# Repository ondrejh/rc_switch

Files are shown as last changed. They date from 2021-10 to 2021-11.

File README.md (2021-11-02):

RC signal (PWM) driven load switch
==================================

## Description

The device is using small mcu (cheapest possible MSP430FR2000) to decode RC signal and switch on the load NMOS tranzistor. Therefor its NPN switch (switching - or gnd).

PCB has no connectors. The servo (3 wires), battery (2 wires) and load (2 wires) cables are soldered directly to solder pads to save space and wheight.

The signal treshold and hysteresis is set in the code (see [main.c](/fw/main.c)). The polarity switching (high or low) can be set by soldering bridge marked "NEG".

## Hardware

### Schematic:

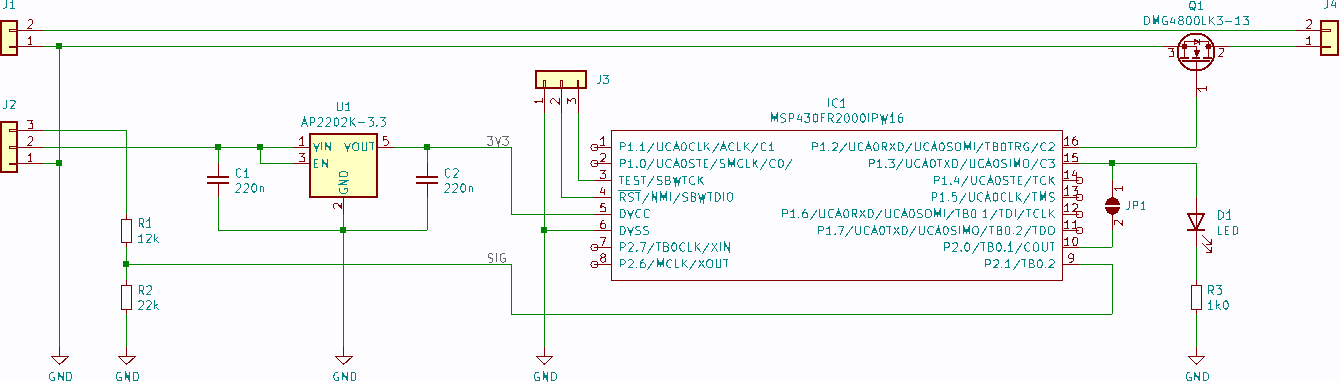
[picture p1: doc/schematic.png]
Schematic


### Assembled printed circuit (visualisation):

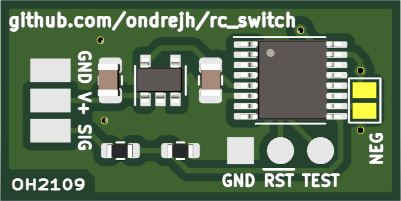
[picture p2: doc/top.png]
PCBA top

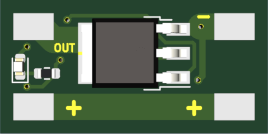
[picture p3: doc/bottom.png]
PCBA bottom


## ToDo:

- describe make process and tools
- describe programming
- create GIF demo

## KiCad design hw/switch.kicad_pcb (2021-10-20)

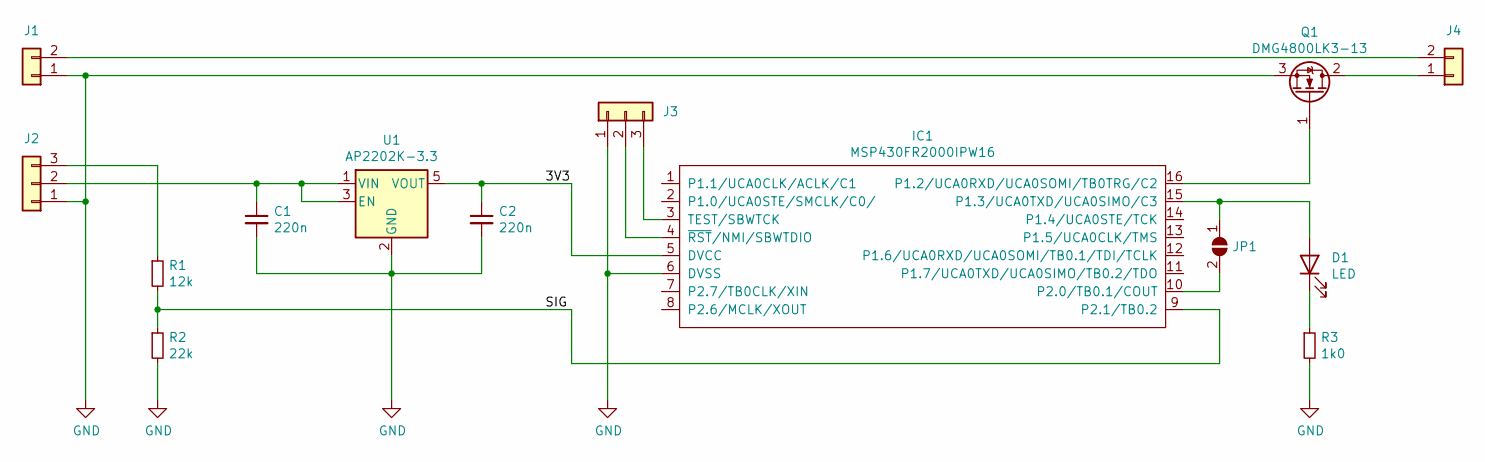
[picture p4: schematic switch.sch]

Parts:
C1, C2: 220n; C_0805_2012Metric
D1: LED; LED_0603_1608Metric
IC1: MSP430FR2000IPW16; TSSOP-16_4.4x5mm_P0.65mm
J1, J4: Conn_01x02; PWR_CON
J2: Conn_01x03; SERVO
J3: Conn_01x03; PROG
JP1: SolderJumper_2_Open; SolderJumper-2_P1.3mm_Open_Pad1.0x1.5mm
Q1: DMG4800LK3-13; TO-252-3_TabPin2
R1: 12k; R_0603_1608Metric
R2: 22k; R_0603_1608Metric
R3: 1k0; R_0603_1608Metric
U1: AP2202K-3.3; SOT-23-5

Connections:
/3V3: C2.1, IC1.5 (DVCC), U1.5 (VOUT)
/SIG: IC1.9 (P2.1/TB0.2), R1.2, R2.1
GND: C1.2, C2.2, IC1.6 (DVSS), J1.1, J2.1, J3.1, Q1.3 (S), R2.2, R3.2, U1.2 (GND)
unnamed: C1.1, J2.2, U1.1 (VIN), U1.3 (EN)
unnamed: D1.1 (K), R3.1
unnamed: D1.2 (A), IC1.15 (P1.3/UCA0TXD/UCA0SIMO/C3), JP1.1 (A)
unnamed: IC1.3 (TEST/SBWTCK), J3.3
unnamed: IC1.4 (~RST~/NMI/SBWTDIO), J3.2
unnamed: IC1.10 (P2.0/TB0.1/COUT), JP1.2 (B)
unnamed: IC1.16 (P1.2/UCA0RXD/UCA0SOMI/TB0TRG/C2), Q1.1 (G)
unnamed: J1.2, J4.2
unnamed: J2.3, R1.1
unnamed: J4.1, Q1.2 (D)

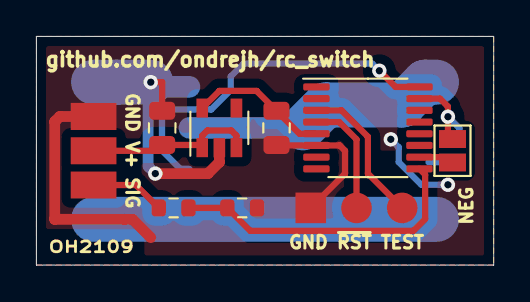
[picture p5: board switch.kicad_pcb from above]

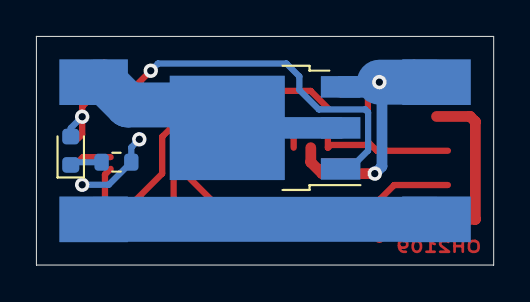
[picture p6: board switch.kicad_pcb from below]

Board: 2 copper layers, 25.4 x 12.7 mm, 14 parts (5 on the bottom side), 13 nets.

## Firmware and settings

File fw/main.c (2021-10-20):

/**
 * program rc spínače
 * program by mel zapínat a vypínat výkonový výstup podle vstupního
 * signálu servo pulsů
 **/

#include <msp430.h>
#include <stdint.h>
#include <stdbool.h>

#define IN (P2IN&BIT1)  // P2.1
#define NEG (P2IN&BIT0) // P2.0

#define POUT (1<<2) // P1.2 = PA.2
#define LED (1<<3) // P1.3 = PA.3

#define ON() do{PAOUT|=(POUT|LED);}while(0)
#define OFF() do{PAOUT&=~(POUT|LED);}while(0)

#define MS2P(x) (x/8)

#define PULSE_MAX (MS2P(2500)) // 2.5ms
#define PULSE_MIN (MS2P(500)) // 0.5ms

#define NO_PULSE_MAX (MS2P(50000)) // 50ms

#define PULSE_TH_LOW (MS2P(1300)) // 1.3ms
#define PULSE_TH_HIGH (MS2P(1700)) // 1.7ms
#define PULSE_HYST (MS2P(20)) // 0.02ms


int main(void)
{
    WDTCTL = WDTPW | WDTHOLD; // vypnout bafana
	
	// IOs 
	PADIR = POUT | LED;
	PAOUT = 0;
	P2REN = 1;
    PM5CTL0 &= ~LOCKLPM5; // aktivace nastaveni IO (magie)
	
	// nastaveni citace
	TBCTL = 0x02E0; // SMCLK, Continuous mode, 1/8

	bool in = false;
	uint16_t pstart = 0;
	
	// detekce negovacího vstupu
	bool neg = false;
	if (NEG) {
		neg = true;
	}
	else {
		PAOUT = LED;
		pstart = TBR;
		while ((TBR - pstart) < 1000) {};
		if (NEG) neg = true;
		PAOUT = 0;
		while ((TBR - pstart) < 5000) {};
	}

	// smyčka
	while(1) {
		uint16_t now = TBR;
		
		bool nin = IN;
		// detekce pulsu
		if (nin != in) {
			if (in) { // sestupna hrana
				uint16_t pulse;
				pulse = now - pstart;
				// validizace pulsu
				if ((pulse < PULSE_MAX) && (pulse > PULSE_MIN)) {
					if (neg) {
						if (pulse < (PULSE_TH_LOW - PULSE_HYST)) ON();
						else if (pulse > (PULSE_TH_LOW + PULSE_HYST)) OFF();
					}
					else {
						if (pulse > (PULSE_TH_HIGH + PULSE_HYST)) ON();
						else if (pulse < (PULSE_TH_HIGH - PULSE_HYST)) OFF();
					}
				}
			}
			else { // nabezna hrana
				pstart = now;
			}
		}
		in = nin;
		
		// vypnout vystup kdyz nejsou pulsy
		if ((now - pstart) > NO_PULSE_MAX) OFF();
	}
}

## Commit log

2021-09-13 repo name
    [switch.kicad_pcb]
2021-09-16 gerber data
    [switch-B_Cu.gbr, switch-B_Mask.gbr, switch-Edge_Cuts.gbr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]
2021-10-20 bom update
    [switch.kicad_pcb, switch.sch]
2021-10-20 switch to MSP430Flasher, test programmig
